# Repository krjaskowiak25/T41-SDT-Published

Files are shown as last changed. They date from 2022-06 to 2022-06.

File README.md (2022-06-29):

# T41-SDT-Published
This is a repository for the published files created for the T41 Software Defined Transceiver (SDT).  The radio is undergoing development by
Dr. Jack Purdum, W8TEE, and Albert Peter, AC8GY.  The primary reference is their book, "Software Defined Radio Transceiver: Theory and Construction
of the T41-ep Amateur Radio SDT." The most recent information, including the book's errata, can be found on the groups.io site,
https://groups.io/g/SoftwareControlledHamRadio.

NOTE...NOTE...NOTE: At the present time, this is not intended to be collaborative development site.  It is a clearing house for the files released for
the T41-SDT.

NOTE...NOTE...NOTE: These files may or may not be production ready and are not advertised to be ready-for-release.  Always assume every file will need
to be reviewed and verified prior to any attempt to use them successfully.

NOTE...NOTE...NOTE: Whenever possible, production-ready files will be maintained as branches to this repository.

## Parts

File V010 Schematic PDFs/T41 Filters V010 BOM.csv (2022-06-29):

Quantity | RefDes | Value | Name
2 | C1, C4 | 56pF | 500V CAP_1206
2 | C2, C3 | 150pF | 500V CAP_1206
11 | C5, C6, C11, C12, C19, C20, C26, C27, C100, C1a, C2a | 0.1uF | CAP_1206
2 | C7, C10 | 82pF | 500V CAP_1206
2 | C8, C9 | 220pF | 500V CAP_1206
2 | C13, C16 | 180pF | 500V CAP_1206
2 | C14, C15 | 390pF | 500V CAP_1206
2 | C21, C24 | 270pF | 500V CAP_1206
2 | C22, C23 | 680pF | 500V CAP_1206
2 | C28, C31 | 470pF | 500V CAP_1206
2 | C29, C30 | 1200pF | 500V CAP_1206
2 | C38, C40 | 1800pF | CAP_1206
1 | C39 | 520pF | CAP_1206
1 | C201 | 56pF | CAP_1206
1 | C202 | 130pF | CAP_1206
5 | D1, D2, D3, D4, D5 | Si 100V | 1N4148 Thru
3 | J2, J6, J9 |  | SMA
1 | J3 |  | IDC16M
5 | K1, K2, K3, K4, K5 |  | RELAY3_DPDT
1 | L1 | 11T T37-6 | IND_IRON_CORE
1 | L2 | 13T T37-6 | IND_IRON_CORE
1 | L3 | 10T T37-6 | IND_IRON_CORE
2 | L4, L6 | 12T T37-6 | IND_IRON_CORE
1 | L5 | 14T T37-6 | IND_IRON_CORE
2 | L7, L9 | 16T T37-6 | IND_IRON_CORE
1 | L8 | 17T T37-6 | IND_IRON_CORE
2 | L11, L13 | 22T T37-6 | IND_IRON_CORE
1 | L12 | 24T T37-6 | IND_IRON_CORE
2 | L14, L16 | 21T T68-2 | IND_IRON_CORE
1 | L15 | 23T T68-2 | IND_IRON_CORE
2 | L24, L25 | 25T T68-2 | IND_IRON_CORE
11 | Pin1, Pin3, Pin4, Pin5, Pin6, Pin7, Pin8, Pin9, Pin10, Pin11, Pin12 |  | PINSHAPE_D50
1 | Pin2
5 | Q1, Q2, Q3, Q4, Q5 |  | BS170 Thru
5 | R1, R2, R3, R4, R5 | 6.8K | RES_1206
89

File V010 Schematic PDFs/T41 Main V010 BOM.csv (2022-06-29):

Quantity | RefDes | Value | Name
25 | 15MFilter, 15Mfilter1, 20MFilter, 20Mfilter1, 40MFilter, 40Mfilter2, 80MFilter, 80Mfilter3, Fan1, Fan2, Key1, Key2, KEY_1, KEY_2, Mute, pin38, PTT, PTT2, Rx/Tx, Rx/Tx1, Rx/Tx_1, Speaker1, Speaker2, Speaker_1, Speaker_2 |  | CON_MALE
4 | Bands..., Display1, Encoders, Encoders1 |  | IDC2x5_Male
3 | C1, C3, C9 | 10uF | CAP_1206
4 | C2, C4, C5, C8 | 0.1uF | CAP_1206
1 | C6 | 1uF | CAP 1206
1 | C10 | 0.001uF | 1206
4 | C100, C102, C106, C303 | 10uF | CAP
3 | C103, C207, C302 | 0.1uF | 1206
1 | C105 | 220uF | CAP
2 | C201, C202 | 0.01uF | 1206
1 | C301 | 100uF | CAP
1 | C305 | 0.22uF | 1206
2 | CLK1, CLK2 |  | SMA COAX_FEMALE
3 | Display, Tune/Filter1, Volume |  | IDC2x5_Cable
3 | Ex_Out, Mic_in, Rec_In |  | Phone Jack
4 | Filter, FineTune, Tune, Volume1 |  | Encoder
2 | L100, L301 |  | 1206 FERRITE_BEAD
18 | Pin204, Pin205, Pin206, Pin207, Pin208, Pin209, Pin210, Pin211, Pin212, Pin214, Pin215, Pin216, Pin217, Pin218, Pin219, Pin220, Pin221, Pin222 |  | PINSHAPE_D50
2 | Pin213, Pin223
1 | Power |  | IDC16M
1 | Q1 |  | BS170
2 | Q101, Q102 |  | 2N2222A
1 | R1 | 100K | RES
4 | R2, R3, R7, R100 | 10K | RES
3 | R8, R9, R10 | 100 | RES
1 | R101 | 7.5K | RES
1 | R104 | 120 | RES
1 | R105 | 82 | RES
1 | R108 | 510 | RES
1 | R110 | 680 | RES
2 | R201, R202 | 4.7K | RES
2 | R301, R302 | 47K | RES
1 | R303 | 10k | Trim pot
1 | Teensy4.1 |  | Teensy 4.1
8 | TP1, TP2, TP3, TP4, TP5, TP6, TP7, TP8 |  | TESTPOINT
1 | U4 |  | TDA7266M
1 | U5 |  | 74HC125
1 | U6 |  | Si5351A
1 | U7 |  | PCM1808
1 | U8 |  | PCM5102
1 | USBHost |  | 1-1734028-1
1 | Y1 | 25MHz | Crystal
122

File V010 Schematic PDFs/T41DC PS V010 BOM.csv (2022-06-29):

Quantity | RefDes | Value | Name
3 | C1, C2, C3 | 10uF | CAP
3 | C4, C5, C6 | 0.1uF | CAP
1 | D1 |  | 10V ZENER
1 | J1 |  | 2x8IDC
1 | Q1 | FQP47p06 | MOSFET_ENH_P
1 | R1 | 100K | RES_1206
2 | TP12, TP14 |  | CON_MALE_2
1 | U1 |  | LM1117-33
1 | U2 |  | LM7805
14

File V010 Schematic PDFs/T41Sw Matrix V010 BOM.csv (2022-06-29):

Quantity | RefDes | Value | Name
2 | C1, C2 | 0.1uF | CAP_1206
1 | R1 | 200 | RES_1206
15 | R2, R3, R4, R5, R6, R7, R8, R9, R10, R11, R12, R13, R14, R15, R16 | 100 | RES_1206
1 | R17 | 10K | RES_1206
3 | S1, S2, S3 |  | 6x6x9mm Tact Tactile Push Button Momentary Micro Sw
15 | S4, S5, S6, S7, S8, S9, S10, S11, S12, S13, S14, S15, S16, S17, S18 |  | 6x6x9mm Tactile PB Mom Micro Switch
37

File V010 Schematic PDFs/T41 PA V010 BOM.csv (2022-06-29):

Quantity | RefDes | Value | Name
28 | C1, C2, C3, C5, C6, C7, C8, C9, C10, C24, C101, C102, C104, C105, C107, C108, C109, C110, C111, C112, C201, C202, C204, C206, C208, C209, C300, C302 | 0.1uF | CAP_1206
1 | C4 | 390 pF | CAP_1206
1 | C11 | 100uF
4 | C103, C106, C203, C207 | 0.47uF | CAP_1206
1 | C205 | 33pF | CAP_1206
1 | C301 | 100uF | CAPAE-4.3x4.3h5.4
9 | D301, D302, D303, D304, D305, D306, D307, D308, D309 |  | DIODE_1N4148
2 | J1, J2 |  | SMA COAX_FEMALE
1 | J3 |  | CON_MALE
2 | J4, J6 |  | HDR-1x2H
1 | J5 |  | HDRF-1x2
2 | J200, J201 |  | CON_FEMALE
1 | JP1 |  | JUMPER
1 | L1 | 0.18uH | 1206
5 | L2, L101, L103, L201, L204 | 2.2uH | 1206
4 | L102, L104, L202, L203 | .33uH | 1206
4 | Q1, Q2, Q3, Q5 |  | 2N3904
2 | Q4, Q302 |  | 2N3906
4 | Q101, Q102, Q201, Q202 |  | IRF510
1 | Q301 |  | TIP127
1 | Q303 |  | IRFU9024
1 | R1 | 4700 | RES_1206
1 | R2 | 5100 | RES_1206
1 | R3 | 200 | RES_1206
3 | R4, R16, R304 | 150 | RES_1206
1 | R5 | 3300 | RES_1206
1 | R6 | 5600 | RES_1206
1 | R7 | 1200 | RES_1206
1 | R8 | 200 | Trim Pot
1 | R9 | 3K | RES_1206
1 | R10 | 680 | RES_1206
2 | R11, R13 | 24K | RES_1206
4 | R12, R15, R301, R302 | 10K | RES_1206
1 | R14 | 48 | RES_1206
1 | R17 | 37 | RES_1206
1 | R19 | 5.5K | RES_1206
4 | R100, R102, R200, R203 | 10K | Trim Pot
2 | R101, R103 | 100 | RES_1206
2 | R106, R107 | 1.1K | RES_1206
2 | R201, R204 | 56 | RES_1206
2 | R202, R205 | 240
1 | R300 | 0.167 | 6 1ohm parallel
1 | R303 | 470 | RES_1206
1 | R306 | 220 | RES_1206
1 | T1 | 4T-P 3T Bi-S | BN43-202
1 | T2 | 10T Bi | FT50 - 43 Toroid
1 | T3 | 4T-P 6T-Bi_S | BN43-202
1 | T4 | 10T | 2x FT50 43 Toroid
1 | T5 | 2T-P 3T-S | BN-43-3312
1 | U1 |  | LM7815CT
1 | U2 |  | LM317T
119

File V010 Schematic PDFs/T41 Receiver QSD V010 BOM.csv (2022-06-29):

Quantity | RefDes | Value | Name
12 | C1, C2, C3, C4, C6, C8, C10, C104, C202, C212, C302, C303 | 0.1uF | CAP_1206
7 | C5, C7, C9, C305, C307, C310, C311 | 10uF | CAP_1206
4 | C203, C207, C210, C211 | 10nF | CAP_1206
4 | C204, C205, C206, C208 | 1uF | CAP_1206
4 | C304, C306, C308, C309 | 68pF | CAP_1206
2 | J1, J2 |  | SMA COAX_FEMALE
1 | J4 |  | 1/8 Phone Jack
1 | J5 |  | 2x8IDC
5 | L1, L2, L3, L4, L5 | Ferrite Bead | 1206
2 | Q1, Q2 |  | 2N3904
1 | R1 | 390 | RES_1206
1 | R2 | 5.6K | RES_1206
1 | R3 | 510 | RES_1206
1 | R4 | 68 | RES_1206
1 | R5 | 200 | RES_1206
4 | R201, R202, R206, R207 | 100 | RES_1206
2 | R203, R208 | 2K | RES_1206
4 | R204, R205, R209, R210 | 10K | RES_1206
8 | R301, R302, R303, R304, R305, R306, R307, R308 | 5.1K | RES_1206
1 | T1 | FT50-43 Toroid | Toroid Xformer
3 | TP1, TP6, TP7 |  | TESTPOINT
1 | U4 |  | 74CBTLV3253PWRE4
1 | U5 |  | 74AC74MTC
1 | U2-3 |  | MC33078BYDT
1 | U3-3 |  | MC33078YDT
73

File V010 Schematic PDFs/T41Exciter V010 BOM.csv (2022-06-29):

Quantity | RefDes | Value | Name
14 | C1, C10, C15, C20, C21, C23, C24, C25, C26, C27, C29, C30, C31, C32 | 0.1uF | CAP_1206
10 | C2, C4, C6, C7, C12, C14, C16, C17, C22, C28 | 10uF | CAP
4 | C3, C11, C33, C34 | 100pF | CAP_1206
4 | C5, C9, C13, C19 | 0.0022uF | CAP_1206
2 | C8, C18 | 1nF | CAP_1206
1 | C35 | 0.1uF | CAP 1206
1 | J1 |  | IDC16M
1 | J2 |  | CON_PHONE_JACK4
2 | J3, J4 |  | SMA COAX_FEMALE
1 | J5 |  | HDR-1x2H
1 | JP1 |  | JUMPER
4 | L1, L2, L3, L4 | Ferrite Bead | 1206
1 | Q1 |  | BS170
4 | R1, R6, R9, R16 | 49.9 | RES_1206
6 | R2, R3, R5, R11, R12, R15 | 10K | RES_1206
2 | R4, R13 | 10k | RES_1206
4 | R7, R14, R17, R18 | 2.2K | RES_1206
2 | R8, R10 | 4.7K | RES_1206
2 | R19, R21 | 10K | RES
1 | R20 | 100K | RES
1 | T1 |  | T37-6 yellow
13 | TP1, TP2, TP3, TP4, TP5, TP6, TP7, TP8, TP9, TP10, TP11, TP12, TP13 |  | TESTPOINT
2 | U1, U2 |  | MC33078YDT
1 | U3 |  | 74CBTLV3253PWRE4
1 | U4 |  | 74AC74MTC
85

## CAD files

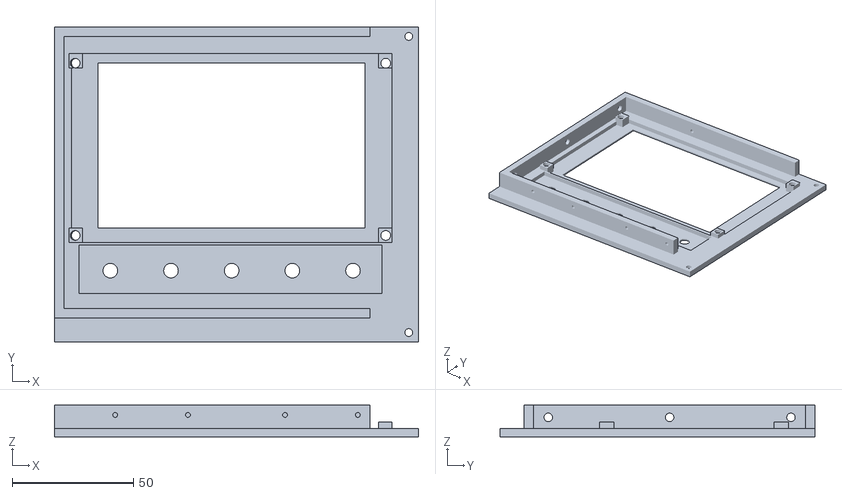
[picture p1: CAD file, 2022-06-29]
V010 5 in case Stl Files/T41 Front left panel V010-Front Panel full.stl
150.0 x 130.0 x 13.0

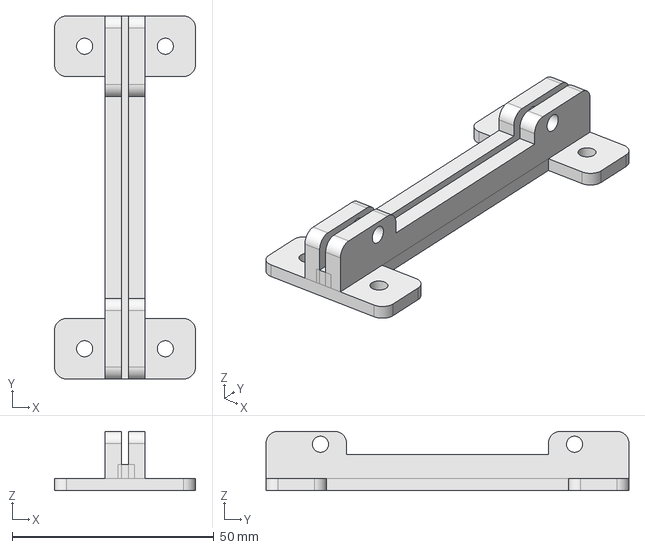
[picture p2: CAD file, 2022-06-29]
V010 5 in case FreeCad Files/PS PCB Mounting Bracket.FCStd
35.0 x 90.0 x 14.7 mm

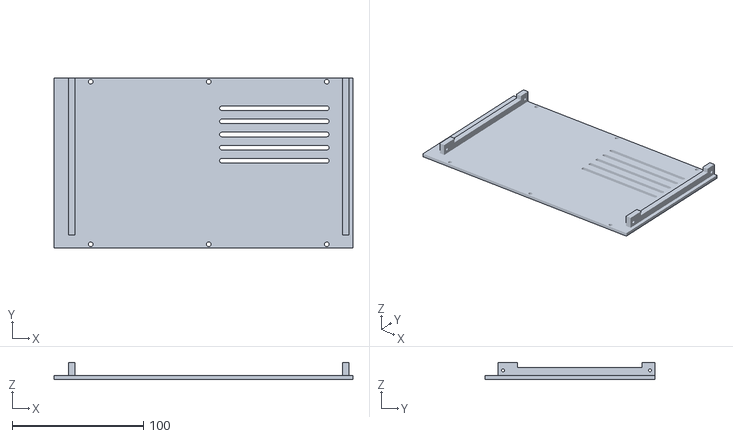
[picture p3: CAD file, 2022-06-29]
V010 5 in case Stl Files/T41 Side Left Panel V010-Body.stl
228.0 x 130.0 x 13.0

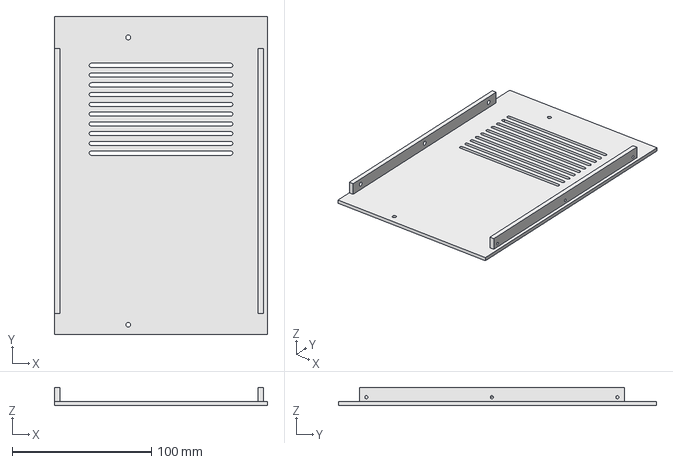
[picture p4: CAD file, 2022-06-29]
V011 7 in case files/T41 Top Right Panel Vents V011.FCStd
153.0 x 228.0 x 13.0 mm

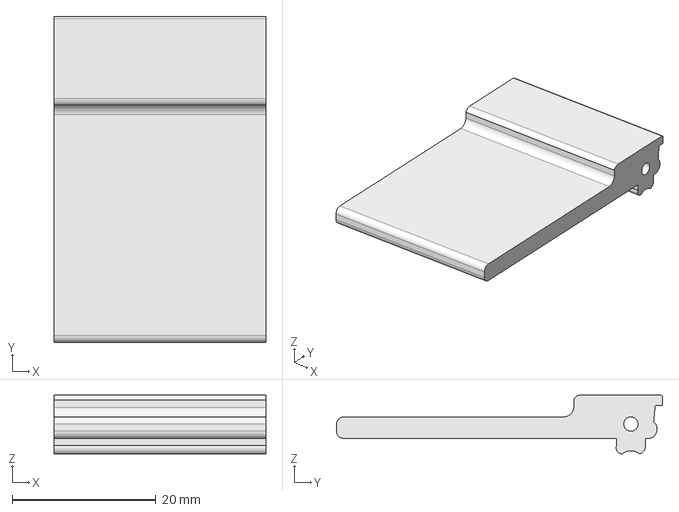
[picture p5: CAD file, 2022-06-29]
V010 5 in case FreeCad Files/T41 Foot V010.FCStd
29.5 x 45.4 x 8.21 mm

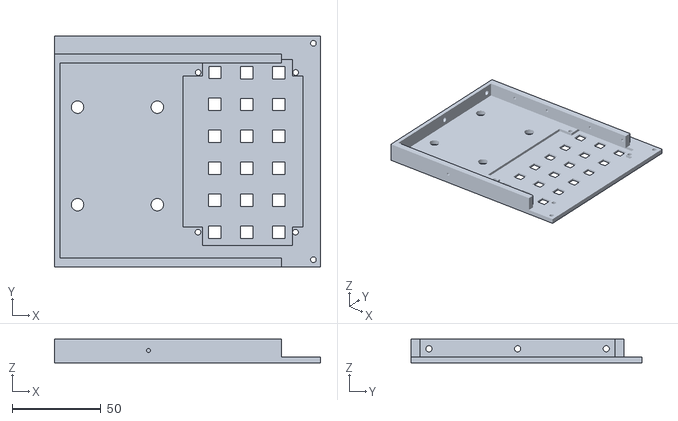
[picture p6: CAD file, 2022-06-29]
V010 5 in case Stl Files/T41 Front Right Panel V010-Front PanelRl.stl
150.0 x 130.0 x 13.5

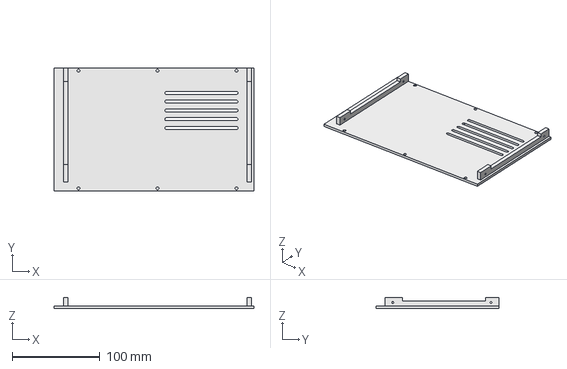
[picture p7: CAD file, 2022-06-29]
V011 7 in case files/T41 7in Side Left PanelV011.FCStd
228.0 x 140.0 x 13.0 mm

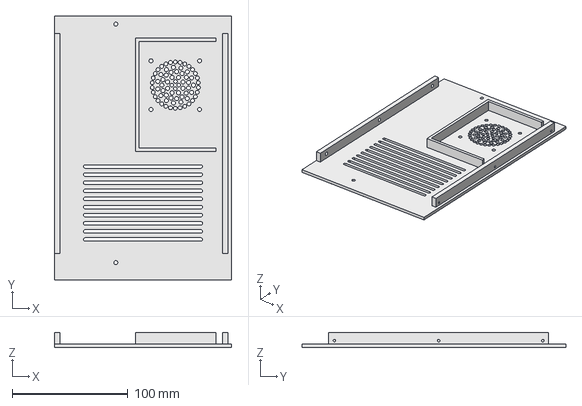
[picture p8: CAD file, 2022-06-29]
V010 5 in case FreeCad Files/T41 Top Left Panel Speaker Vents V010.FCStd
153.0 x 228.0 x 13.0 mm

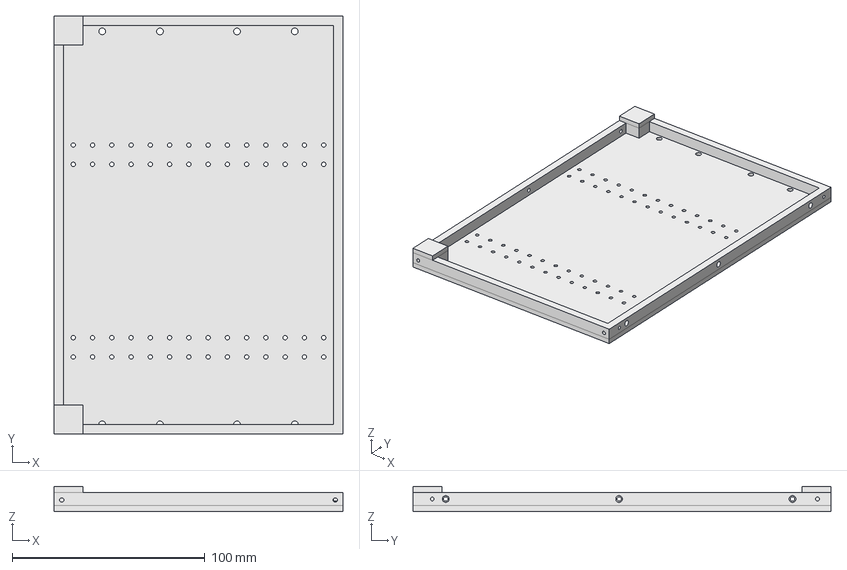
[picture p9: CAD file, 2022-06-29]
V010 5 in case FreeCad Files/T41 Base Right V010.FCStd
150.0 x 217.0 x 13.0 mm

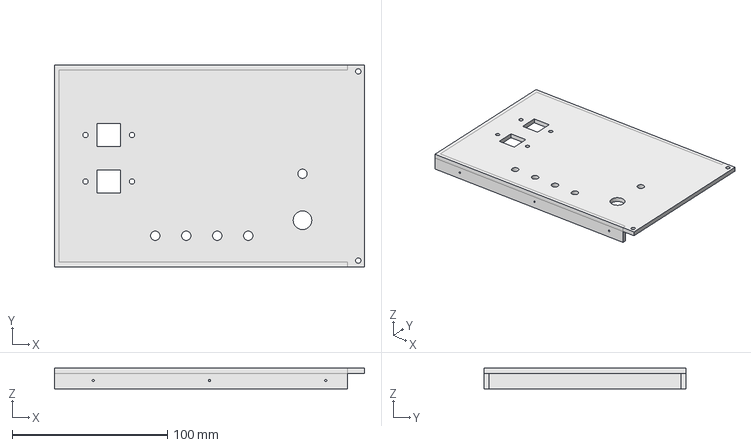
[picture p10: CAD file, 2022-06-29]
V011 7 in case files/T41 7inBack left panel V011.FCStd
200.0 x 130.0 x 13.5 mm

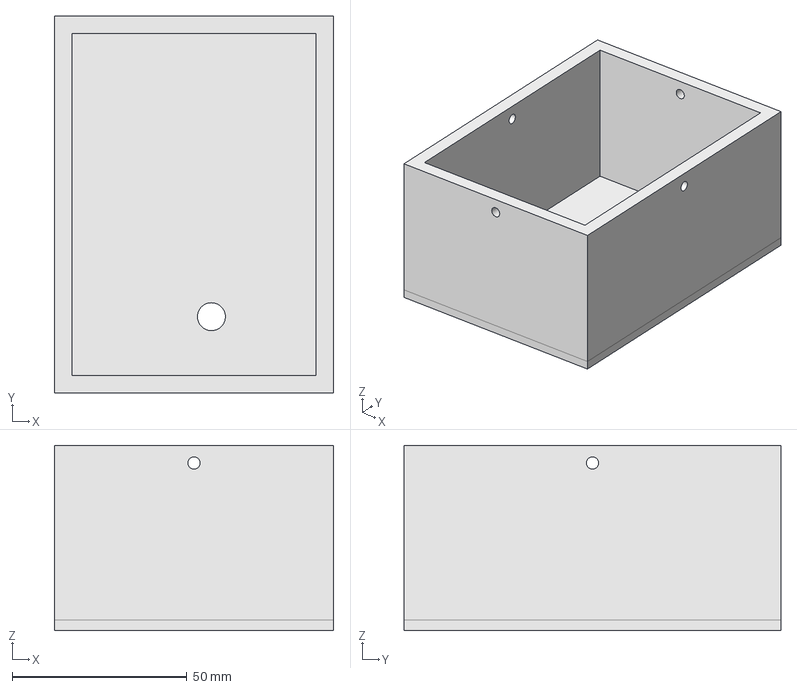
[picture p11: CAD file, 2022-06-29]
V011 7 in case files/Speaker Box V011.FCStd
80.0 x 108.0 x 53.0 mm

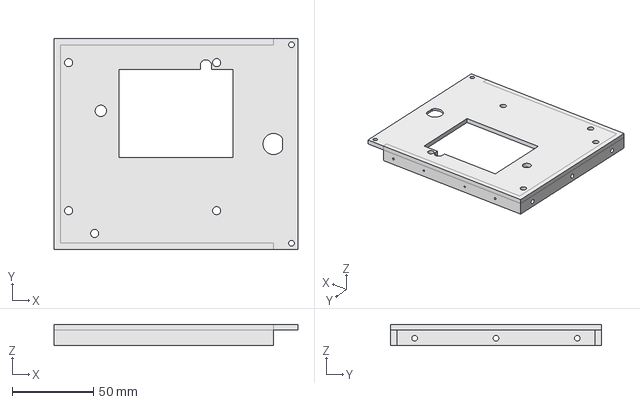
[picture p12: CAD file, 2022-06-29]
V011 7 in case files/T41 7IN Back Right Panel V011.FCStd
150.0 x 130.0 x 13.0 mm

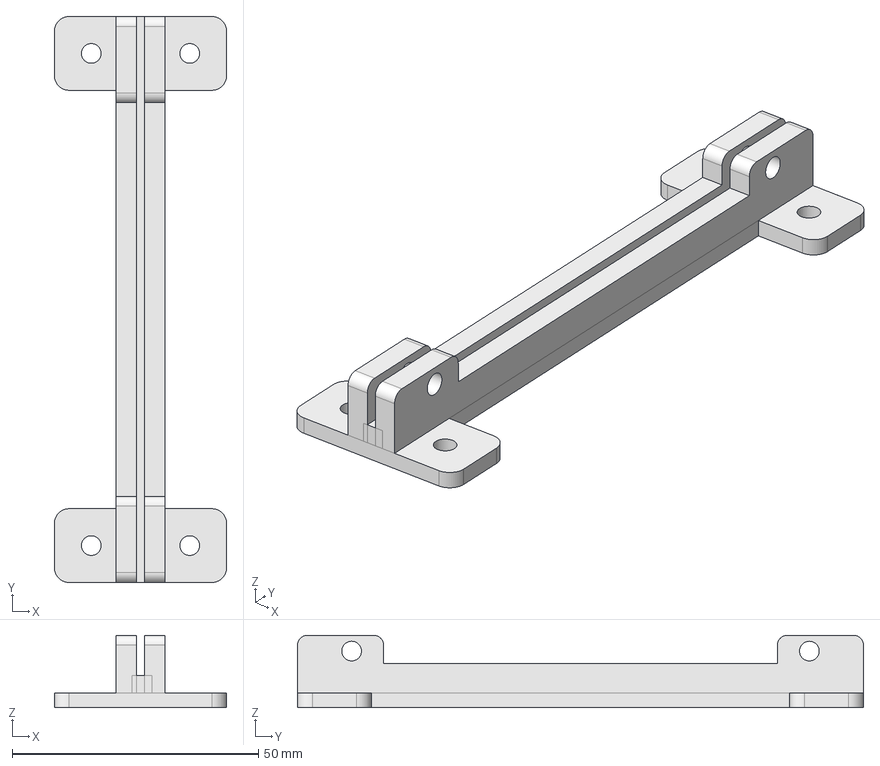
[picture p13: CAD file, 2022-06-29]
V010 5 in case FreeCad Files/Mounting Bracket V010.FCStd
35.0 x 115.0 x 14.7 mm

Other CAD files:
V010 5 in case Stl Files/PS PCB Mounting Bracket-Body V010.stl
V010 5 in case Stl Files/T41 Top Left Panel Speaker Vents V010-Body.stl
V010 5 in case FreeCad Files/T41 Front left panel V010.FCStd
V010 5 in case Stl Files/T41 Foot V010-Body.stl
V010 5 in case Stl Files/Mounting Bracket V010-Body.stl
V010 5 in case FreeCad Files/BNC washer.FCStd
V010 5 in case FreeCad Files/Speaker Box V10.FCStd
V010 5 in case FreeCad Files/T41 Back Left Panel V010.FCStd
V010 5 in case FreeCad Files/T41 Back Right Panel V010.FCStd
V010 5 in case FreeCad Files/T41 Base Left V010.FCStd
V010 5 in case FreeCad Files/T41 Front Right Panel V010.FCStd
V010 5 in case FreeCad Files/T41 Side Left Panel V010.FCStd
V010 5 in case FreeCad Files/T41 Side Right Panel V010.FCStd
V010 5 in case FreeCad Files/T41 Top Right Panel Vents V010.FCStd
V010 5 in case FreeCad Files/T41 stand V010.FCStd
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

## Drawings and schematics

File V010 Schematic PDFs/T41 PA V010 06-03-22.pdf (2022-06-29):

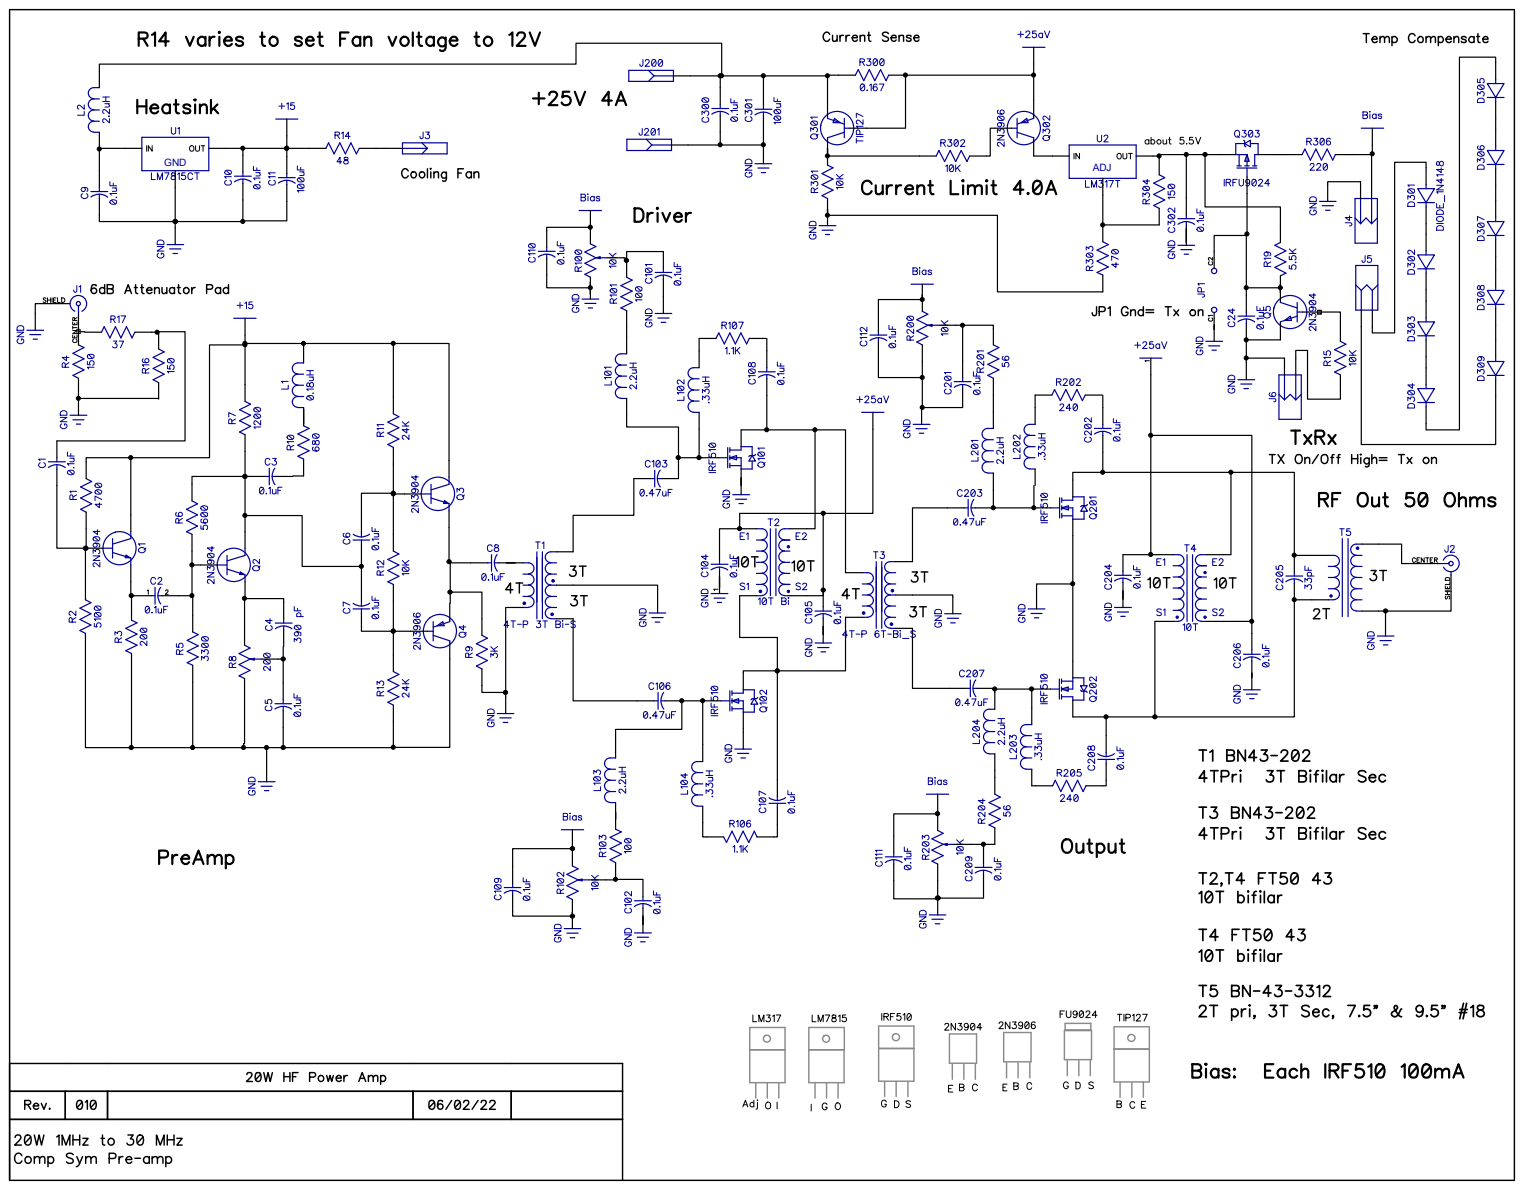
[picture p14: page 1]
GND; ADJ

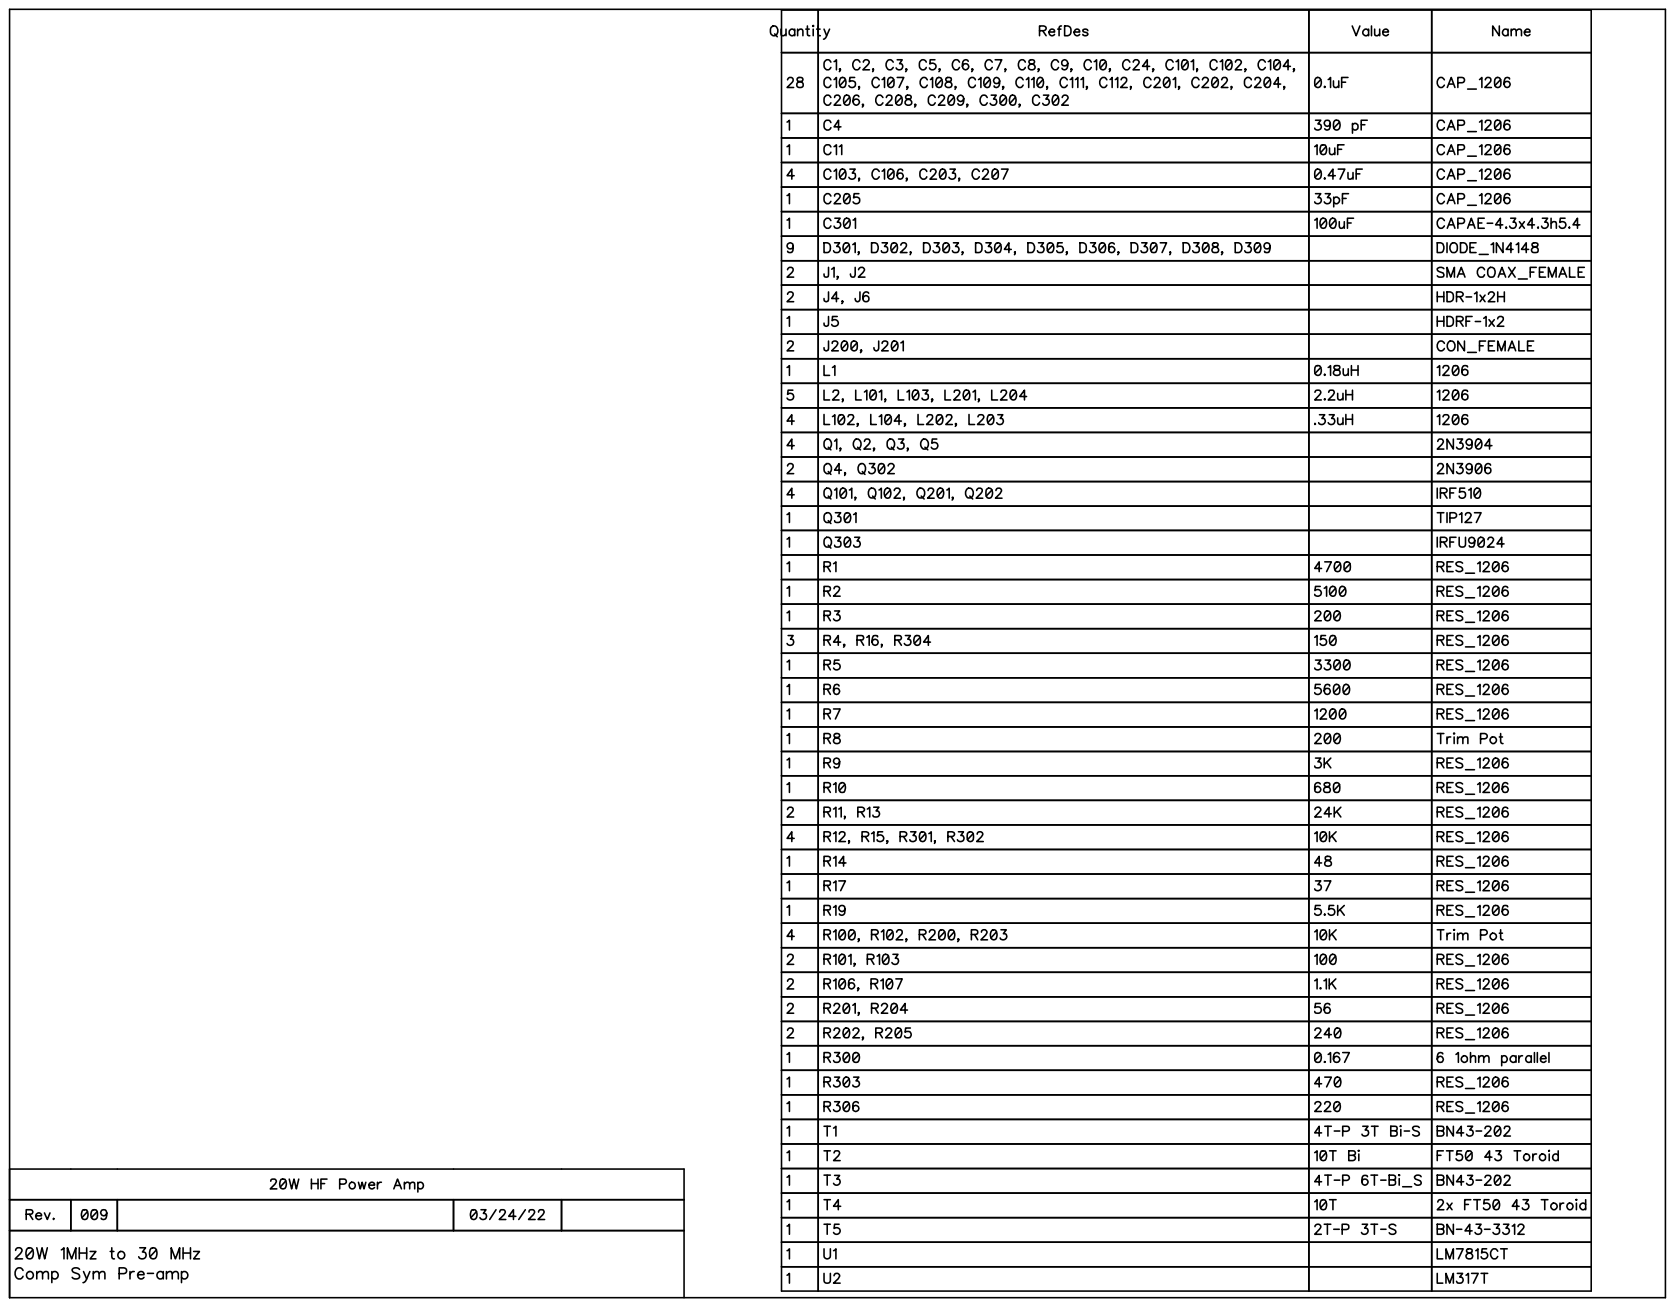
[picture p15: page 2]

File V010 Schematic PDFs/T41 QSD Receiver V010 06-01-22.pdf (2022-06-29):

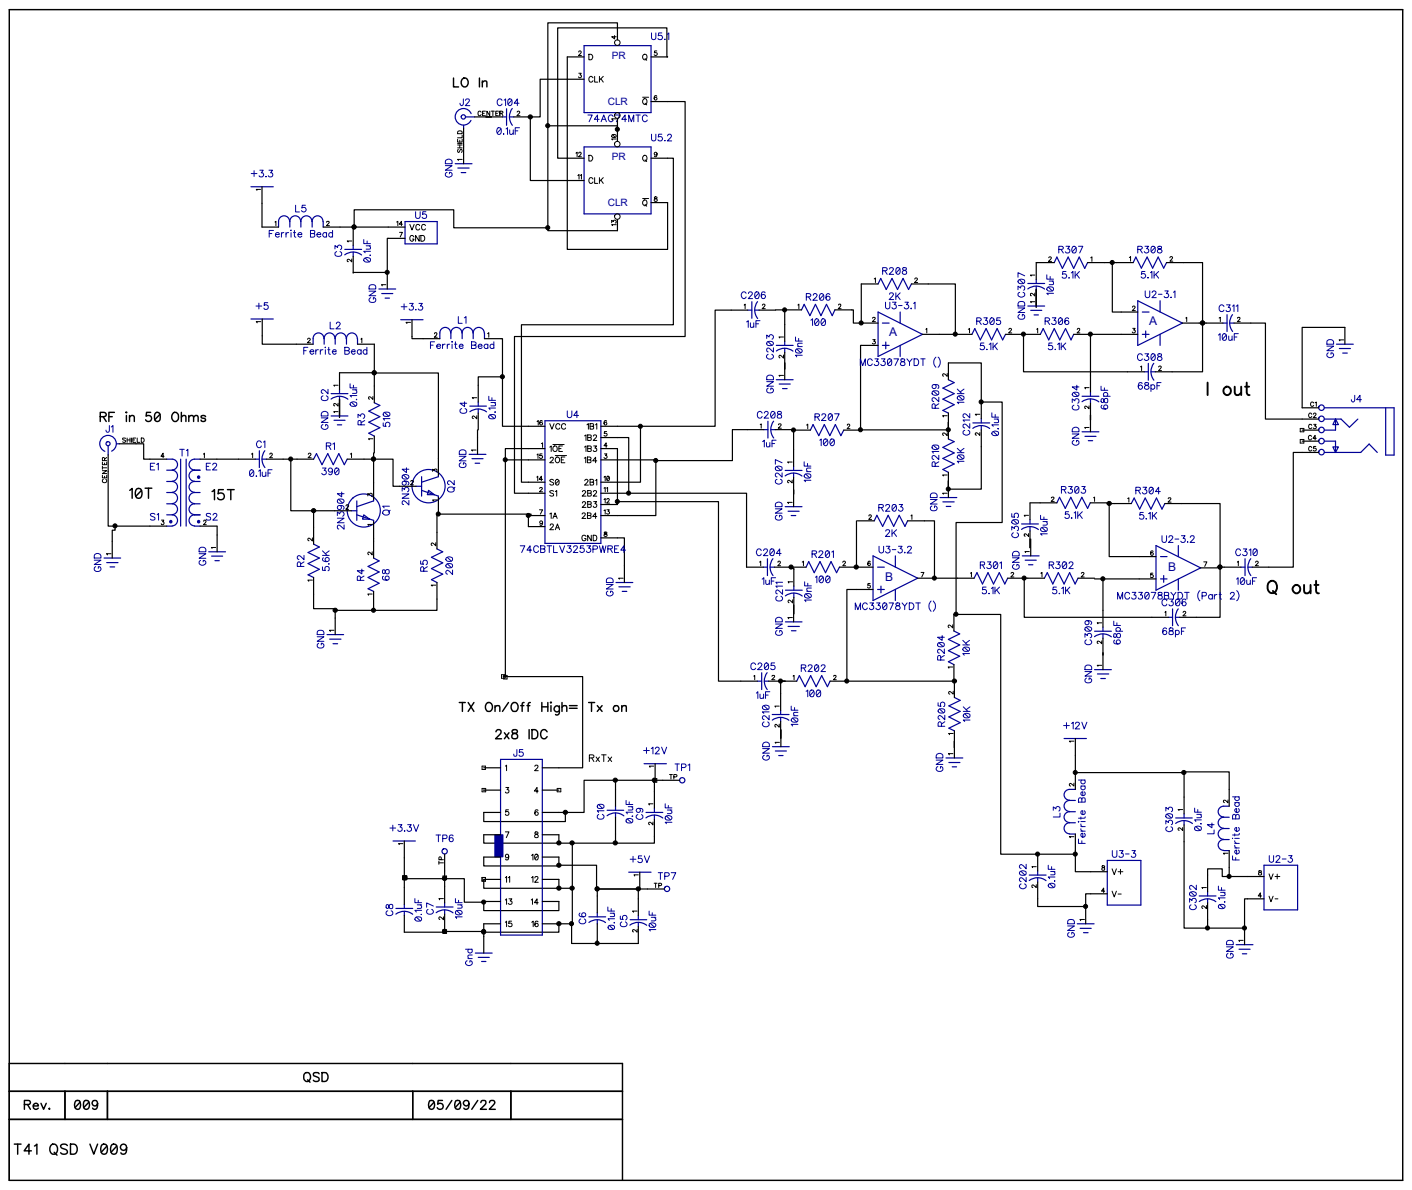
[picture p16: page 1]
CLR

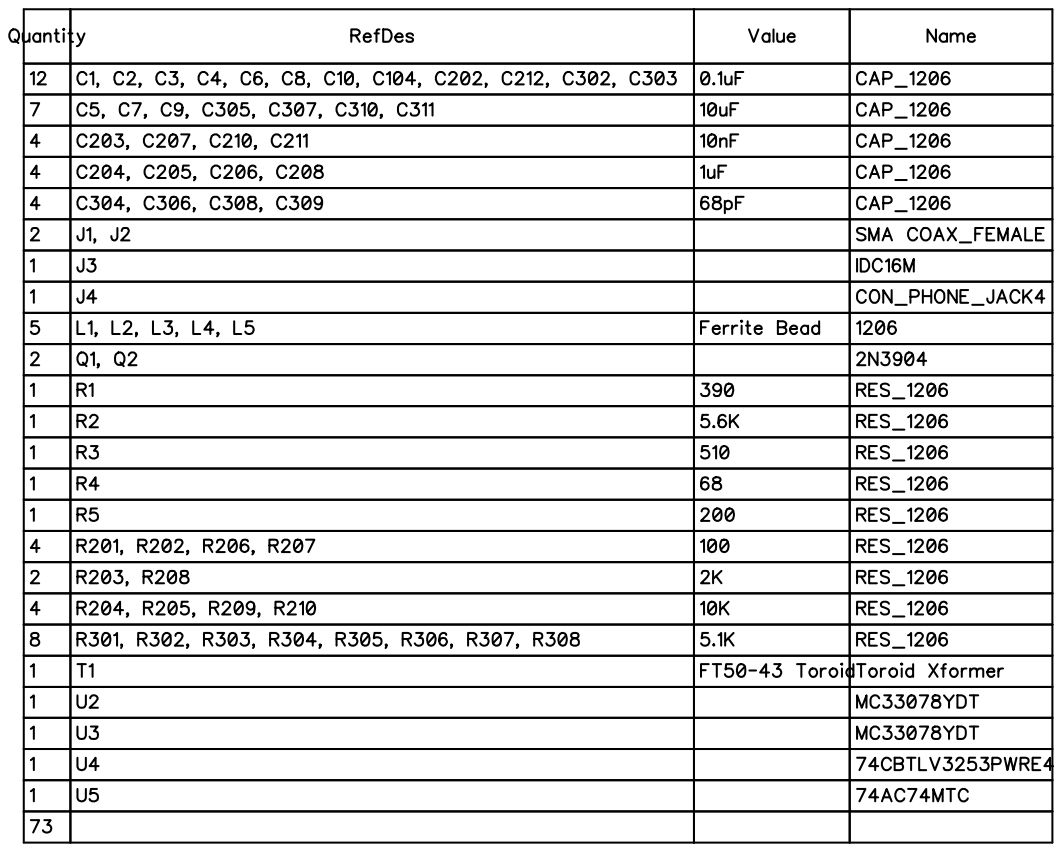
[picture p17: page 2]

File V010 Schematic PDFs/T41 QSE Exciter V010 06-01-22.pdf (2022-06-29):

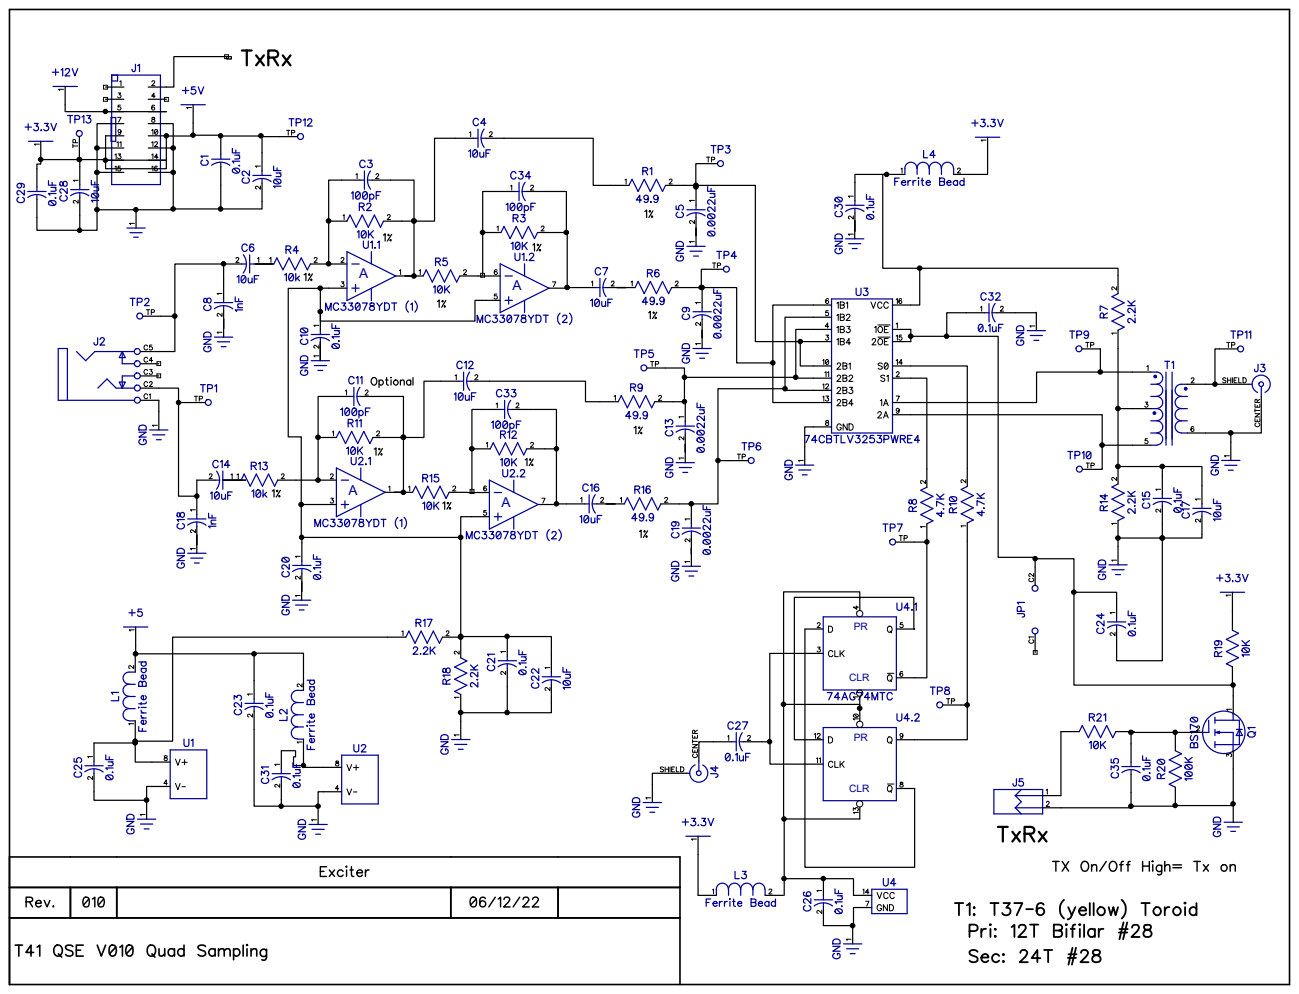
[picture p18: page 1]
CLR

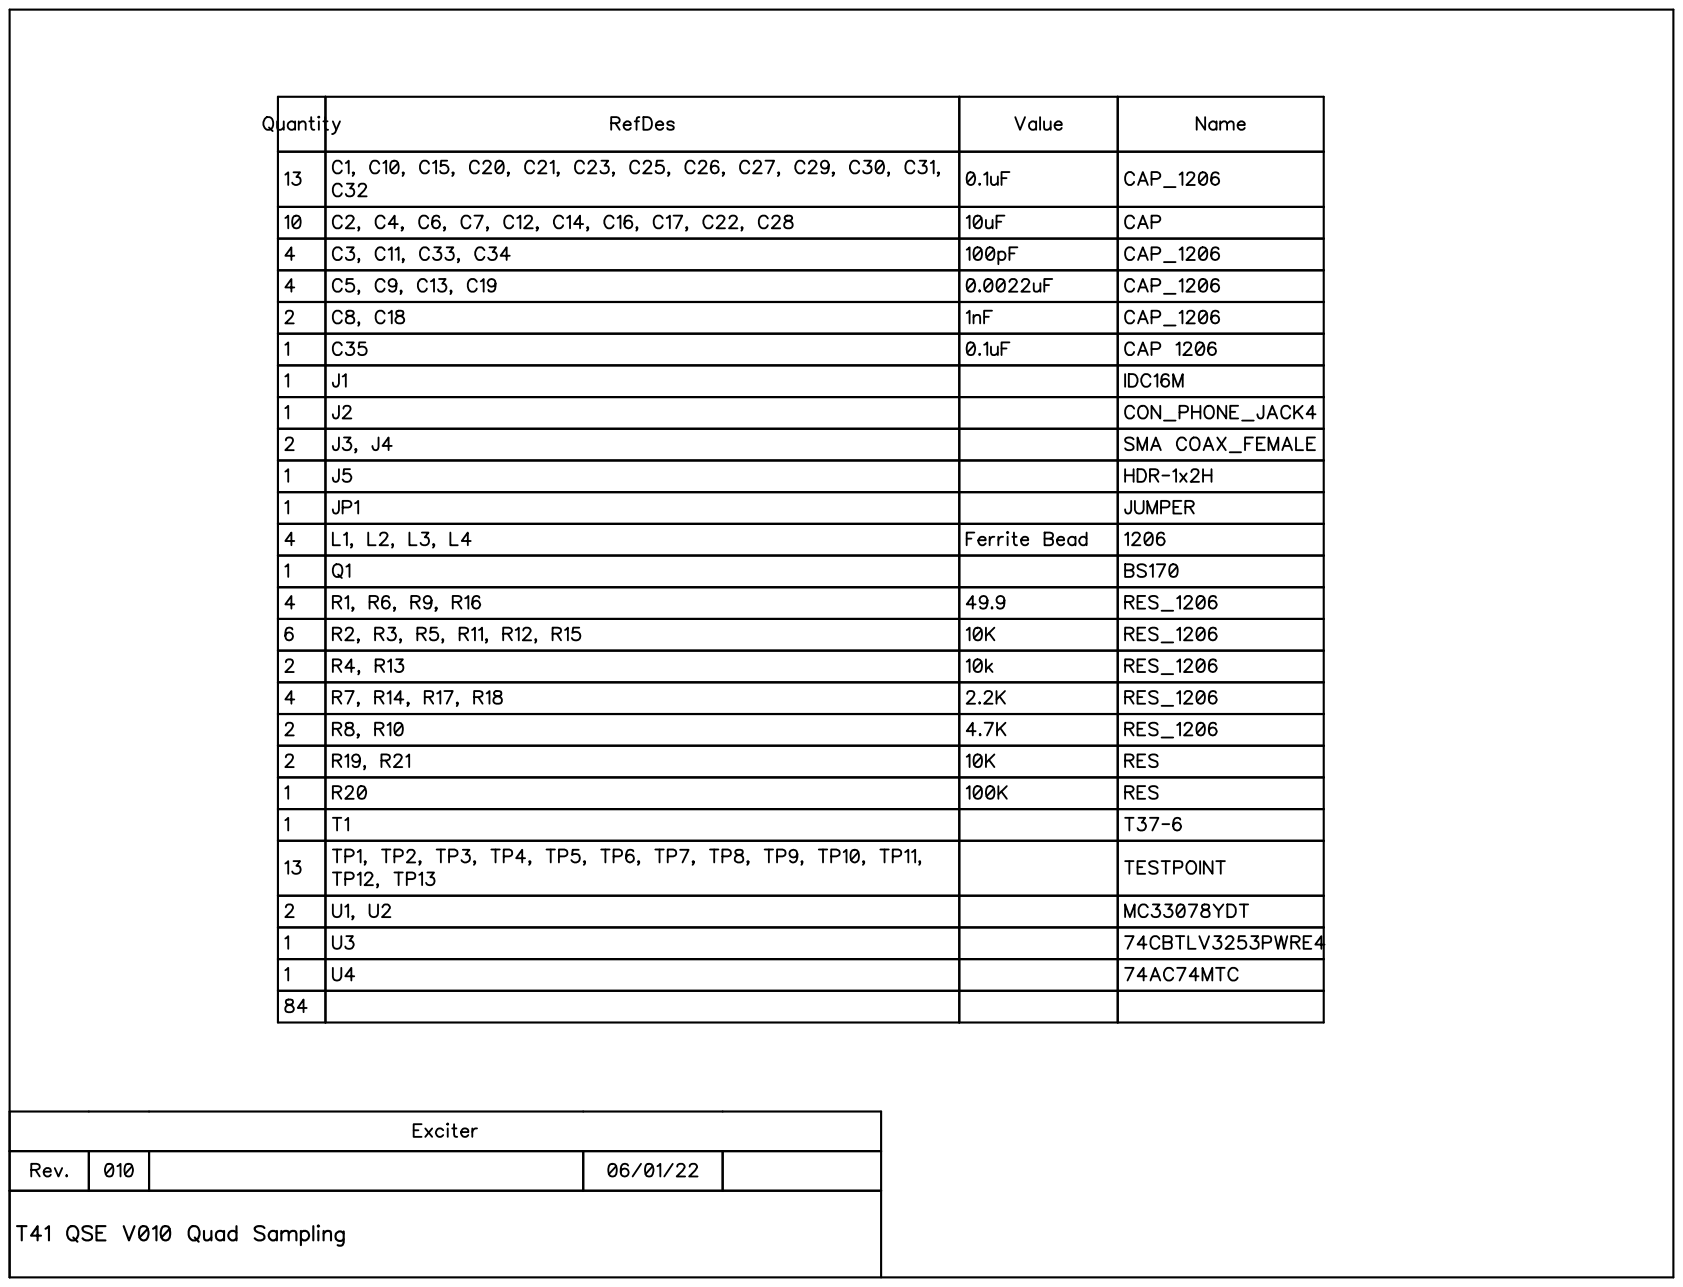
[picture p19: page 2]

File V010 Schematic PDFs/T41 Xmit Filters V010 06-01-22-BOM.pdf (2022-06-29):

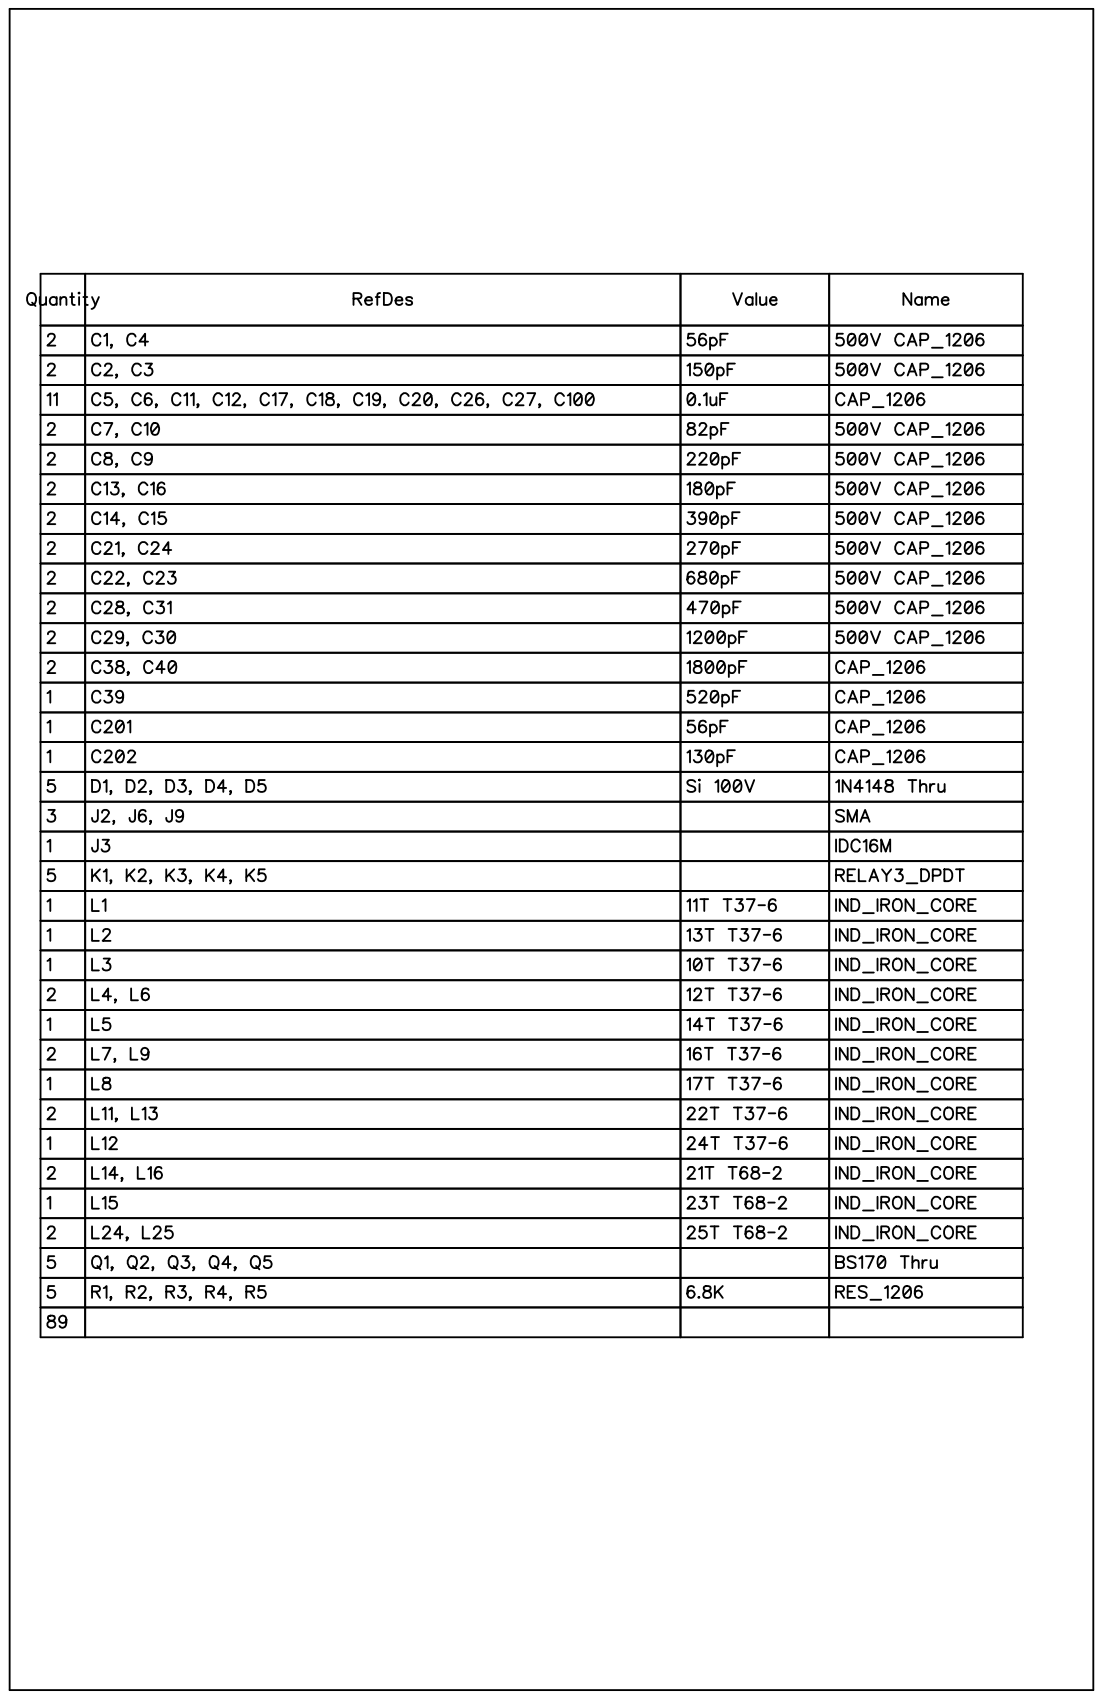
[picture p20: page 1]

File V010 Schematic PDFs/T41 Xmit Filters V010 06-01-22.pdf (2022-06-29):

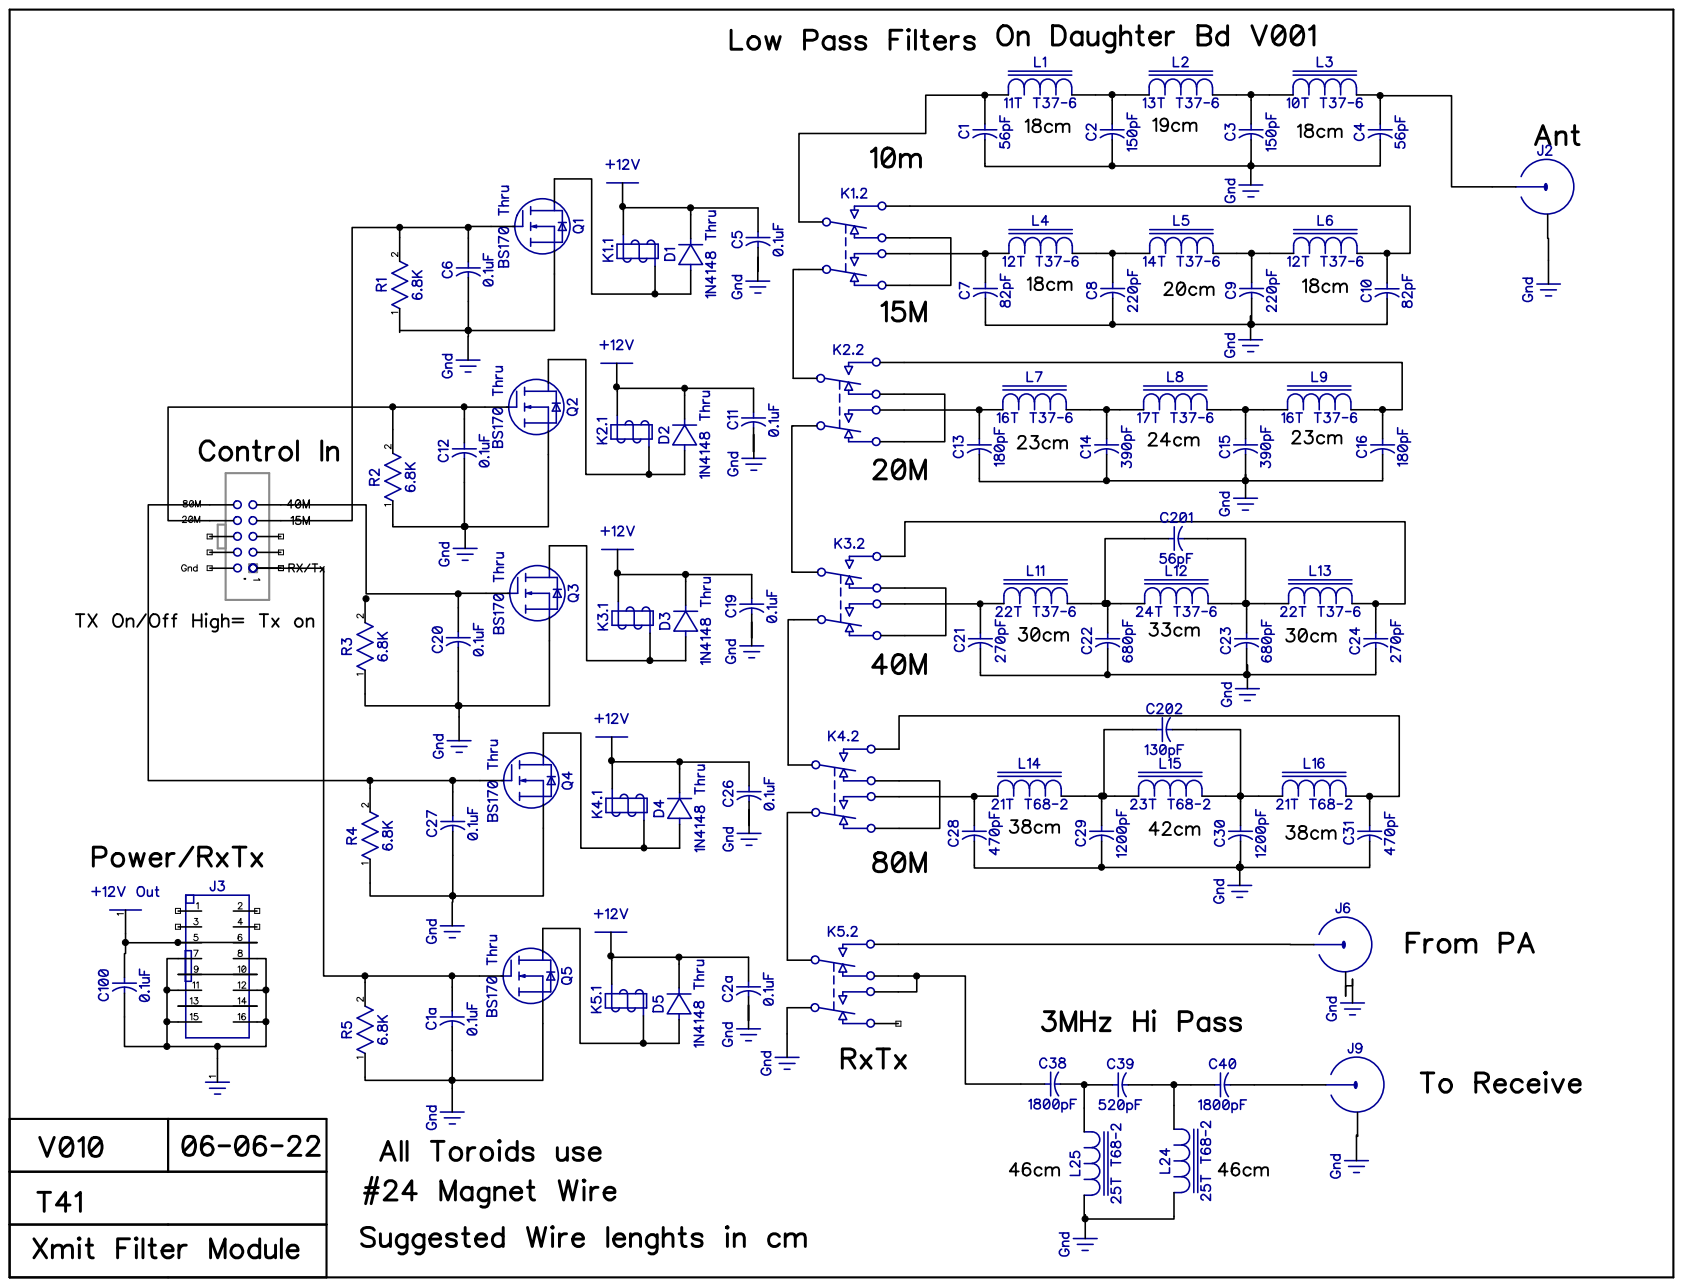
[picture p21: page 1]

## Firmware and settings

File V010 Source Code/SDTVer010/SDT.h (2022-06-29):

#ifndef BEENHERE
#define BEENHERE  //RA8875_DISPLAYRA8875_DISPLAY

//======================================== Library include files ========================================================
#include <Adafruit_GFX.h>
#include "Fonts/FreeMonoBold24pt7b.h"
#include "Fonts/FreeMonoBold18pt7b.h"
#include "Fonts/FreeMono24pt7b.h"
#include <Audio.h>
#include <TimeLib.h>                                // Part of Teensy Time library
#include <Wire.h>
#include <SPI.h>																		// https://github.com/etherkit/Si5351Arduino
#include <SD.h>
#include <Metro.h>
#include <Bounce.h>
#include <arm_math.h>
#include <arm_const_structs.h>
#include <si5351.h>                                 // https://github.com/etherkit/Si5351Arduino
#include <Encoder.h>
#include <Rotary.h>                                 // https://github.com/brianlow/Rotary
#include <stdio.h>
#include <stdlib.h>
#include <string.h>
//#include <hardware/teensy/avr/libraries/Adafruit_GFX/Fonts/FreeMono18pt7b.h>                         // In Adafrui_GFX
#include <util/crc16.h>                             //mdrhere
#include <utility/imxrt_hw.h>                       // for setting I2S freq, Thanks, FrankB!
#include <EEPROM.h>

//======================================== Symbolic Constants for Debugging and Version Control ========================
#define VERSION                     "V010  "
#define RIGNAME                     "T41-EP SDT"
#define SPLASH_DELAY                1000L         // Probably should be 4000 to actually read it
#define RIGNAME_X_OFFSET            580
#define T4                                        // Says we are using a Teensy 4 or 4.1
#define RA8875_DISPLAY              1             // Comment out if not using RA8875 display

#define DEBUG                       1             // This must be uncommented for ANY debugging statements to work
//#define STORE_SWITCH_VALUES                       // Uncomment to save the analog switch values for your push button matrix

#define OFF                         0
#define ON                          1


//#define DEBUG_JACK
//#define DEBUG1
//#define DEBUG2
//#define DEBUG3
//#define DEBUG4
//#define DEBUG6
//#define DEBUG7
//#define DEBUG8
//#define DEBUG9
#define NUMBER_OF_ELEMENTS(x) (sizeof(x)/sizeof(x[0]))
#define NEW_SI5351_FREQ_MULT    1UL


//======================================== Symbolic constants ==========================================================

// These constants are used by the voltage divider network so only 1 analog pin is used for the 16 option switches. These may need
// to be changed for the exact value for your system. They are initialized in the INO file.

#define BUSY_ANALOG_PIN              39     // This is the analog pin that controls the 16 switches
#define NOTHING_TO_SEE_HERE         950     // If the analog pin is greater than this value, nothing's going on
#define BOGUS_PIN_READ               -1     // If no push button read
#define WIGGLE_ROOM                  15     // This is the number of pixels within which a switch analog value must fall
#define SWITCH_DEBOUNCE_DELAY       50L     // Milliseconds for the switch to settle down
#define NUMBER_OF_SWITCHES           16     // Number of push button switches
#define CHAR_HEIGHT                  32
#define PIXELS_PER_EQUALIZER_DELTA   10     // Number of pixeks per detent of encoder for equalizer changes
#define AUDIO_PLOT_CEILING          119     // (SPECTRUM_BOTTOM - AUDIO_SPECTRUM_TOP)

#define TOP_MENU_COUNT               16     // Menus to process
#define MAX_FAVORITES                10     // Max number of favorite frequencies stored in EEPROM
#define PRIMARY_MENU                  0
#define SECONDARY_MENU                1
#define SELECTED_INDEX                3     // This is the index for MENU_OPTION_SELECT

/*
  const char *topMenus[]                    = {"CW",              "Display Choices", "Spectrum Set",   "AGC",        "NR Set",
                                             "IQ Manual",       "EQ Rec Set",   "EQ Xmt Set",     "Mic Comp",   "Freq Cal",
                                             "Noise Reduction", "RF Set",       "Audio Post Proc","VFO Select", "EEPROM",
                                             "Noise Floor",    "Unused 1"
                                            };
*/
#define MENU_OPTION_SELECT           0     // These are the expected values from the switch ladder
#define MAIN_MENU_UP                 1
#define BAND_UP                      2
#define ZOOM                         3
#define MAIN_MENU_DN                 4
#define BAND_DN                      5
#define FILTER                       6
#define DEMODULATION                 7
#define SET_MODE                     8
#define NOISE_REDUCTION              9
#define NOTCH_FILTER                10
#define DISPLAY_OPTIONS             11
#define INCREMENT                   15
#define NOISE_FLOOR                 13
#define UNUSED_1                    14
#define UNUSED_2                    12
//=======================================================
//#define XPIXELS             320           // This is for the standard 2.8" display
//#define YPIXELS             240
//#define XPIXELS             480           // This is for the standard 3.5" display
//#define YPIXELS             320
#define XPIXELS               800           // This is for the 5.0" display
#define YPIXELS               480
#define PIXELHEIGHT           20            // Used in fillRec() to erase a line

#define SPECTRUM_LEFT_X       3            // Used to plot left edge of spectrum display  AFP 12-14-21
#define WATERFALL_LEFT_X      SPECTRUM_LEFT_X

#ifdef RA8875_DISPLAY // -------------------------------------             Standard display

#define CLIP_AUDIO_PEAK       115           // The pixel value where audio peak overwrites S-meter

#define SPECTRUM_RES          512
#define SPECTRUM_TOP_Y        100           // Start of spectrum plot space
#define SPECTRUM_HEIGHT       150           // This is the pixel height of spectrum plot area without disturbing the axes
#define SPECTRUM_BOTTOM       (SPECTRUM_TOP_Y + SPECTRUM_HEIGHT - 3)
#define AUDIO_SPECTRUM_TOP    129
#define AUDIO_SPECTRUM_BOTTOM SPECTRUM_BOTTOM
#define MAX_WATERFALL_WIDTH   512           // Pixel width of waterfall
#define MAX_WATERFALL_ROWS    170           // Waterfall rows
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
